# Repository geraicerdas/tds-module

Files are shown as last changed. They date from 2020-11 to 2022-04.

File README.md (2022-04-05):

### Repository Content
* **/firmware** : Arduino example codes (.ino)
* **/hardware** : Schematic files (.pdf) some of older version included Eagle design files (.sch and .brd)
* **/production** : gerber file for pcb manufacturing

You can purchase this product from  


# TDS Module

TDS (Total Dissolved Solids) indicates how many milligrams of soluble solids are dissolved in one liter of water. In general, the higher the TDS value, the more soluble solids are dissolved in water. This module can be used in DIY water quality application, such as domestic water analysis and hydroponics. The latest version already have temperature compensation for better accuracy.

<p float="left">
 

 
</p>

## How To Use
For the hardware you will need :
- Arduino or other compatible microcontroller
- TDS module with TDS probe and waterproof DS18B20
- Jumper wires

(optional : if you want to use Arduino Library) In the Arduino IDE, make sure :
- you have installed Library : [GravityTDS](https://github.com/DFRobot/GravityTDS) by DFRobot (This library tested on Arduino UNO, and will not work with Arduino Leonardo, ESP32)

Connect the TDS module to the MCU
| Arduino / Other MCU | TDS Module |
| --- |:---|
| 5V / 3.3V | VCC |
| Analog Input Pin | TDS |
| Digital Input Pin | TEM |
| GND | GND |

Upload the code in the firmware folder, and you will get the temperature and compensated TDS value of the water on the Serial Monitor

## Notice
- The probe can not to be used in water above 55 degrees centigrade.
- The probe can not be too close to the edge of the container, otherwise it will affect the reading

## Development logs
V3.0
- Add 3P PH2.0 connector for waterproof temperature sensor DS18B20
- Change 3P terminal to 4P terminal for additional temperature output pin

V2.1
- Rearrange component placement for better layout, fixing wrong decoupling capacitor position
- Change PCB color

V2.0
- Change PCB shape

V1.0
- Initial design

## PCB and Parts

If you want to make your self, just download the gerber file in production folder. Send it to your fav pcb manufacturer. And dont forget to get the Bill of materials :
|Qty | Part Name | Parts | MPN |
| --- |:---|:---| -----:|
|9|Capacitor 0603 100nF|C1, C2, C6, C7, C9, C11, C13, C16, C18|
|3|Capacitor 0603 10uF|C8, C10, C12|
|1|Capacitor 0603 1nF|C15|
|2|Capacitor 0603 1uF|C14, C17|
|2|Capacitor 0603 4.7uF|C4, C5|
|1|Capacitor 3216 100uF|C3|
|2|Resistor 0603 100K-1%|R4, R10|
|7|Resistor 0603 10K-1%|R5, R6, R7, R8, R9, R11, R12|
|1|Resistor 0603 1M-1%|R1|
|1|Resistor 0603 4K7-1%|R14|
|1|Resistor 0603 5.6K-1%|R2, R13|
|1|Resistor 0603 6.8K-1%|R3|
|5|Diode SOD-323 1N4148|D1, D2, D3, D4, D5|
|1|SMD LED 0805|L1|
|1|LMV324 SO-14|U1|
|1|TPS60400 SOT-23-5|U2|
|1|CD4060-BM SO-16|U3|
|1|XC6206P302MR SOT-23|U4|
|1|XH2.5 2P SMD connector|J3|
|1|PH2.0 3P SMD connector|J5|
|1|Teminal Connector 4P 5.08|J6|

Below is the previous version of our TDS Module. We keep this for your references.

### Version 2.1

<p float="left">
 

 
</p>

### Version 1.0

<p float="left">
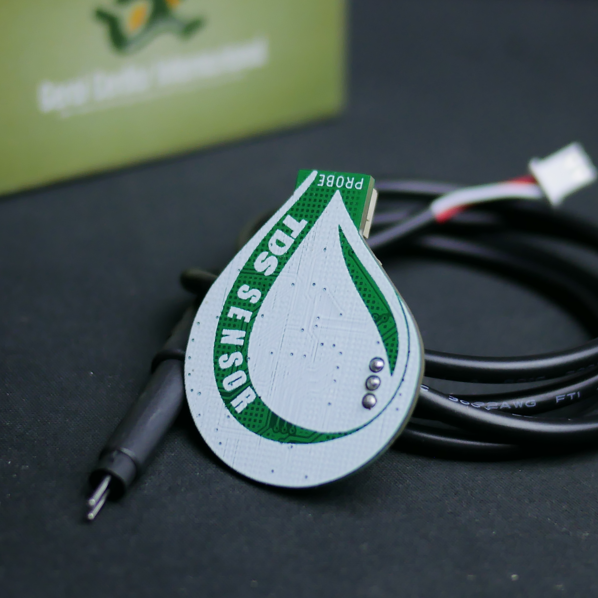
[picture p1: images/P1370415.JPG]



</p>

## License
*We invests time and resources providing this open-source hardware, please support us by purchasing our products.*

*Designed by **[Insan Sains](https://www.youtube.com/insansains)** for **[Gerai Cerdas](https://geraicerdas.com)**, with contributions from the open source community. Creative Commons Attribution/Share-Alike, all text above must be included in any redistribution. See license.txt for additional information.*

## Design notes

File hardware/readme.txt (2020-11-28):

For some reason the schematic with bottom silkscreen is larger than allowable github file size,
so the bottom silkscreen removed to reduce it size.

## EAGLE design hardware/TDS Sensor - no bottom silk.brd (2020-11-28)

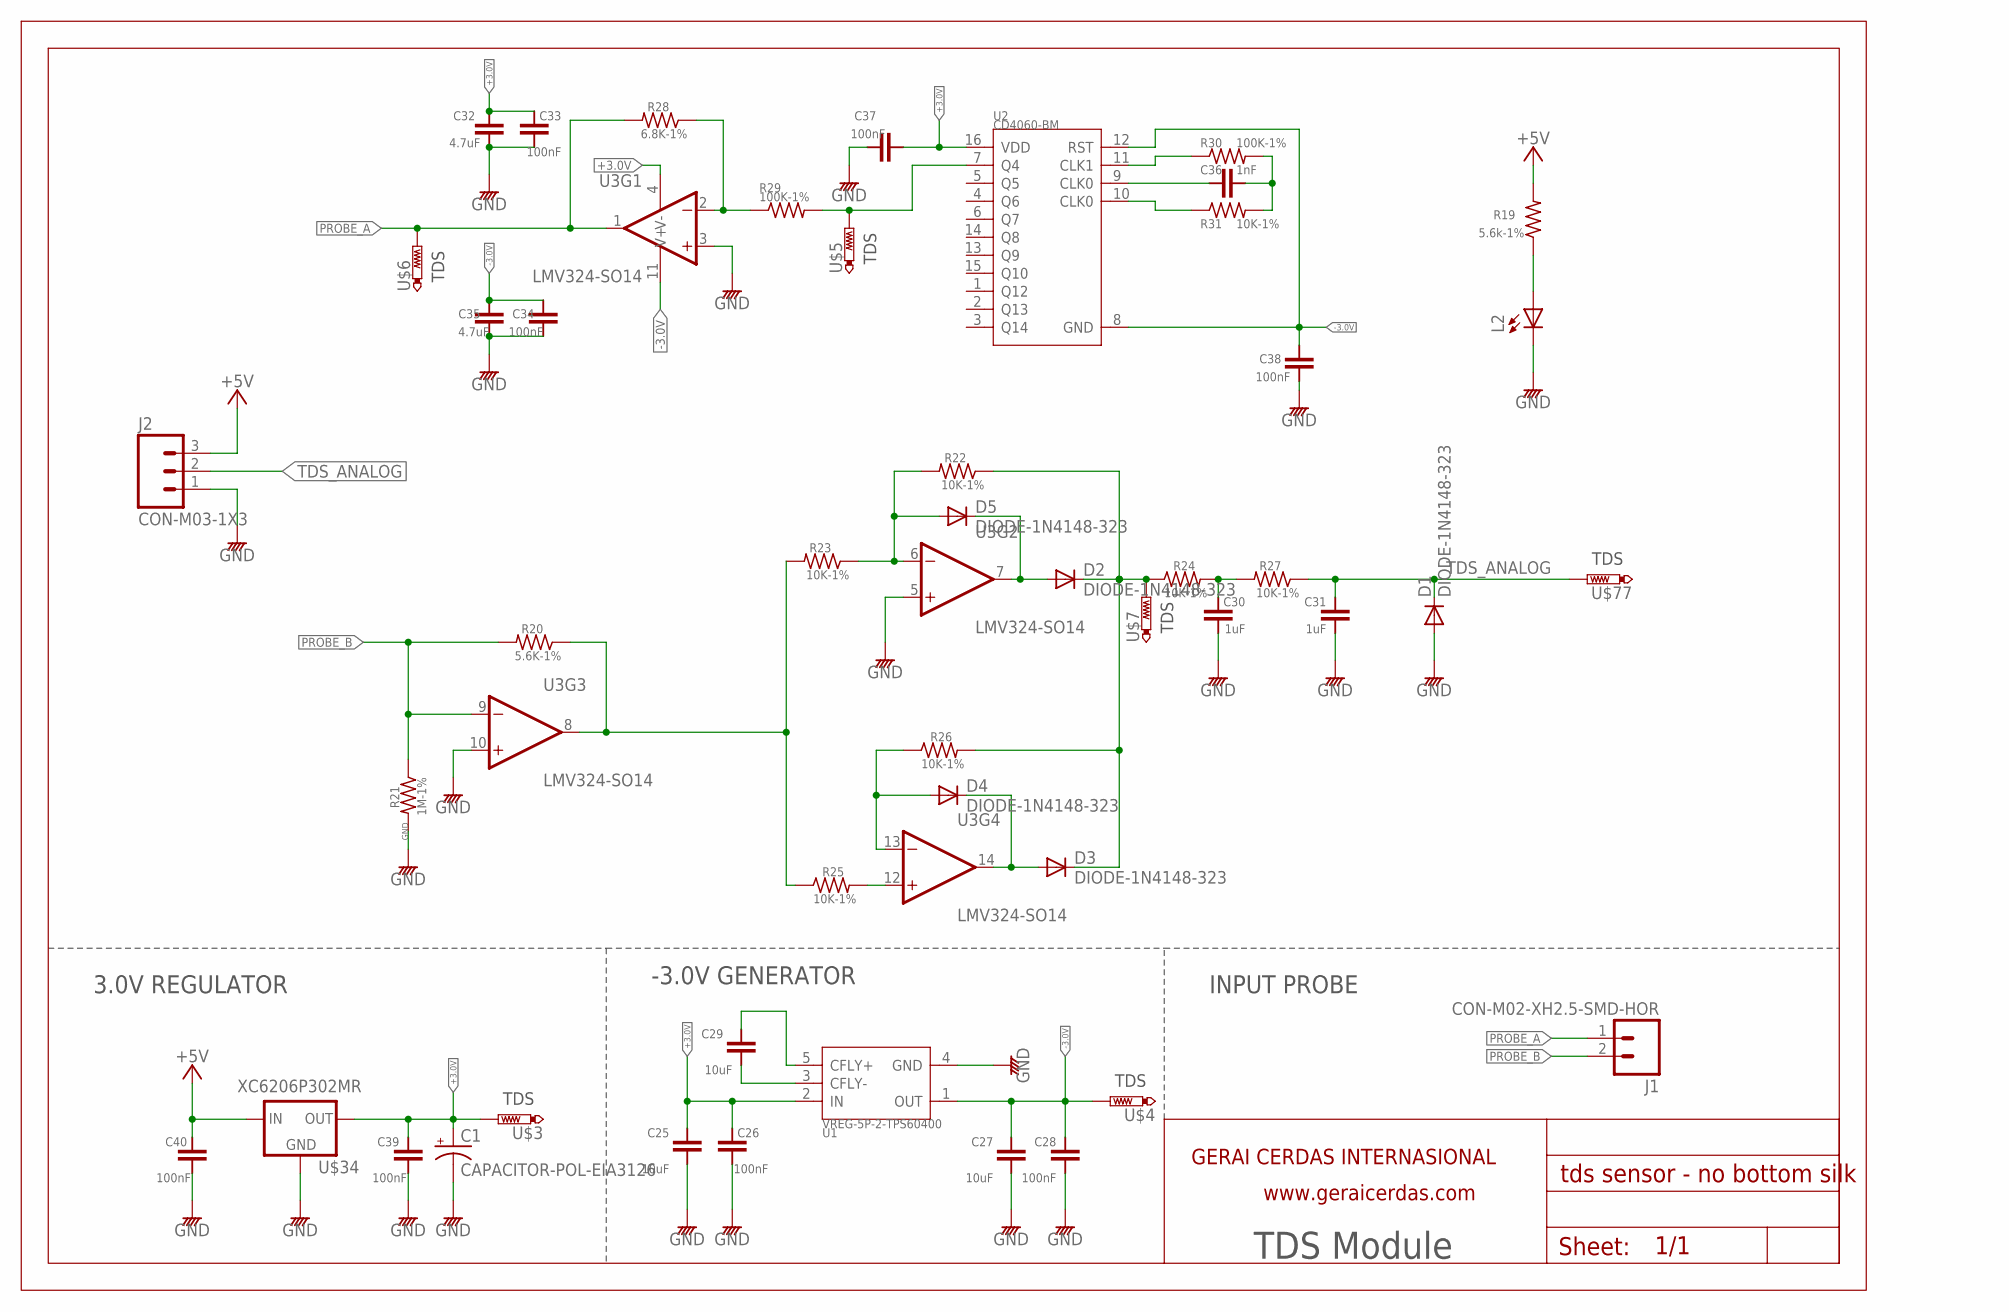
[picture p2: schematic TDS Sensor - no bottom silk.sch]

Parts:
C1: CAPACITOR-POL-EIA3126; EIA3126
C25, C27, C29: 10uF; C0603
C26, C28, C33, C34, C37, C38, C39, C40: 100nF; C0603
C30, C31: 1uF; C0603
C32, C35: 4.7uF; C0603
C36: 1nF; C0603
D1, D2, D3, D4, D5: DIODE-1N4148-323; SOD-323
J1: CON-M02-XH2.5-SMD-HOR; JST-XH2.5-2P-SMD-HORZ
J2: CON-M03-1X3; CON-M03X1
L2: LED-SMD0805; LED0805
R19: 5.6k-1%; R0603
R20: 5.6K-1%; R0603
R21: 1M-1%; R0603
R22, R23, R24, R25, R26, R27, R31: 10K-1%; R0603
R28: 6.8K-1%; R0603
R29, R30: 100K-1%; R0603
U1: VREG-5P-2-TPS60400; SOT-23-5
U2: CD4060-BM; SO-16
U3: LMV324-SO14; SO-14
U$3, U$4, U$5, U$6, U$7, U$77: TDS; TESTPAD_2.54
U$28: FRAME; A4-HOR
U$34: XC6206P302MR; SOT-23

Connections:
+3.0V: C1.A (+), C25.2, C26.2, C32.2, C33.2, C37.1, C39.2, U1.2 (IN), U2.16 (VDD), U3.4 (V+), U$3.TP, U$34.2 (OUT)
+5V: C40.2, J2.3, R19.2, U$34.3 (IN)
-3.0V: C27.2, C28.2, C34.2, C35.2, C38.2, U1.1 (OUT), U2.8 (GND), U2.12 (RST), U3.11 (V-), U$4.TP
GND: C1.C (-), C25.1, C26.1, C27.1, C28.1, C30.1, C31.1, C32.1, C33.1, C34.1, C35.1, C37.2, C38.1, C39.1, C40.1, D1.A, J2.1, L2.C, R21.2, U1.4 (GND), U3.3 (+IN), U3.5 (+IN), U3.10 (+IN), U$34.1 (ADJ)
unnamed: R25.2, U3.12 (+IN)
unnamed: L2.A, R19.1
unnamed: D5.A, R22.2, R23.1, U3.6 (-IN)
unnamed: D2.A, D5.C, U3.7 (OUT)
unnamed: D2.C, D3.C, R22.1, R24.1, R26.2, U$7.TP
unnamed: D4.A, R26.1, U3.13 (-IN)
unnamed: D3.A, D4.C, U3.14 (OUT)
unnamed: R20.1, R23.2, R25.1, U3.8 (OUT)
unnamed: C30.2, R24.2, R27.2
unnamed: R28.1, R29.1, U3.2 (-IN)
unnamed: C29.2, U1.5 (CFLY+)
unnamed: R30.1, U2.11 (CLK1)
unnamed: C36.1, U2.9 (CLK0)
unnamed: R31.1, U2.10 (CLK0)
unnamed: C36.2, R30.2, R31.2
unnamed: R29.2, U2.7 (Q4), U$5.TP
unnamed: C29.1, U1.3 (CFLY-)
PROBE_A: J1.1, R28.2, U3.1 (OUT), U$6.TP
PROBE_B: J1.2, R20.2, R21.1, U3.9 (-IN)
TDS_ANALOG: C31.2, D1.C, J2.2, R27.1, U$77.TP

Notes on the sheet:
TDS Module
INPUT PROBE
3.0V REGULATOR
-3.0V GENERATOR

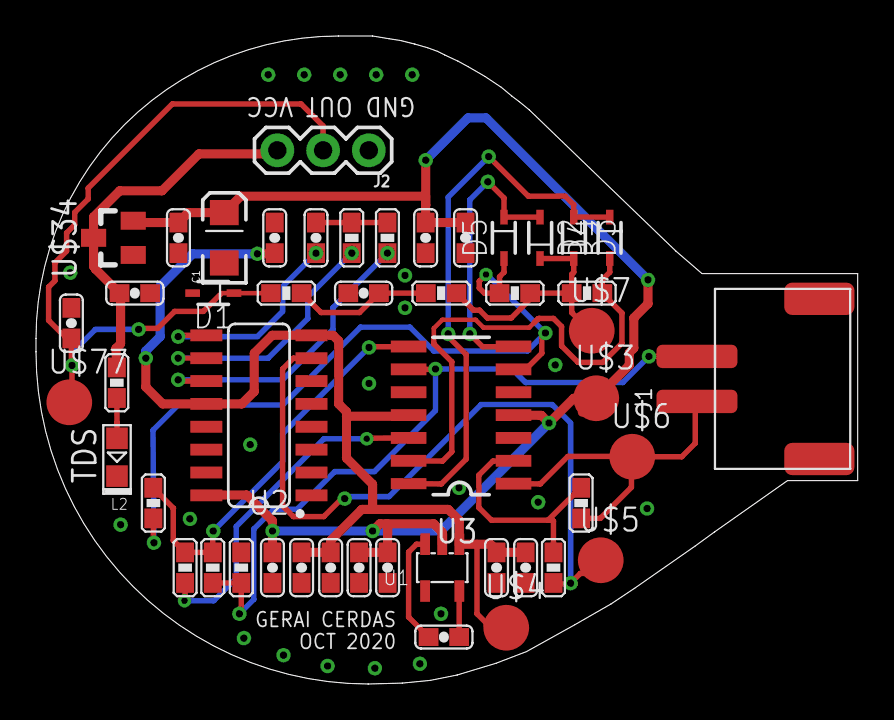
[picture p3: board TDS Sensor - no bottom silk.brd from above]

Board: 2 copper layers, 45.6 x 36.0 mm, 49 parts (0 on the bottom side), 24 nets.

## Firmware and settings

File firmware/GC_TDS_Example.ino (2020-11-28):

/***************************************************
 DFRobot Gravity: Analog TDS Sensor / Meter For Arduino
 <https://www.dfrobot.com/wiki/index.php/Gravity:_Analog_TDS_Sensor_/_Meter_For_Arduino_SKU:_SEN0244>

 Created 2017-8-22
 By Jason <jason.ling@dfrobot.com@dfrobot.com>

 GNU Lesser General Public License.
 See <http://www.gnu.org/licenses/> for details.
 All above must be included in any redistribution

 /***********Notice and Trouble shooting***************
 1. This code is tested on Arduino Uno and Leonardo with Arduino IDE 1.0.5 r2 and 1.8.2.
 2. More details, please click this link: <https://www.dfrobot.com/wiki/index.php/Gravity:_Analog_TDS_Sensor_/_Meter_For_Arduino_SKU:_SEN0244>
 ****************************************************/

#define TdsSensorPin A2
#define VREF 5.0      // analog reference voltage(Volt) of the ADC
#define SCOUNT  30           // sum of sample point
int analogBuffer[SCOUNT];    // store the analog value in the array, read from ADC
int analogBufferTemp[SCOUNT];
int analogBufferIndex = 0,copyIndex = 0;
float averageVoltage = 0,tdsValue = 0,temperature = 25;

void setup()
{
    Serial.begin(115200);
    pinMode(TdsSensorPin,INPUT);
}

void loop()
{
   static unsigned long analogSampleTimepoint = millis();
   if(millis()-analogSampleTimepoint > 40U)     //every 40 milliseconds,read the analog value from the ADC
   {
     analogSampleTimepoint = millis();
     analogBuffer[analogBufferIndex] = analogRead(TdsSensorPin);    //read the analog value and store into the buffer
     analogBufferIndex++;
     if(analogBufferIndex == SCOUNT) 
         analogBufferIndex = 0;
   }   
   static unsigned long printTimepoint = millis();
   if(millis()-printTimepoint > 800U)
   {
      printTimepoint = millis();
      for(copyIndex=0;copyIndex<SCOUNT;copyIndex++)
        analogBufferTemp[copyIndex]= analogBuffer[copyIndex];
      averageVoltage = getMedianNum(analogBufferTemp,SCOUNT) * (float)VREF / 1024.0; // read the analog value more stable by the median filtering algorithm, and convert to voltage value
      float compensationCoefficient=1.0+0.02*(temperature-25.0);    //temperature compensation formula: fFinalResult(25^C) = fFinalResult(current)/(1.0+0.02*(fTP-25.0));
      float compensationVolatge=averageVoltage/compensationCoefficient;  //temperature compensation
      tdsValue=(133.42*compensationVolatge*compensationVolatge*compensationVolatge - 255.86*compensationVolatge*compensationVolatge + 857.39*compensationVolatge)*0.5; //convert voltage value to tds value
      //Serial.print("voltage:");
      //Serial.print(averageVoltage,2);
      //Serial.print("V   ");
      Serial.print("TDS Value:");
      Serial.print(tdsValue,0);
      Serial.println("ppm");
   }
}
int getMedianNum(int bArray[], int iFilterLen) 
{
      int bTab[iFilterLen];
      for (byte i = 0; i<iFilterLen; i++)
      bTab[i] = bArray[i];
      int i, j, bTemp;
      for (j = 0; j < iFilterLen - 1; j++) 
      {
      for (i = 0; i < iFilterLen - j - 1; i++) 
          {
        if (bTab[i] > bTab[i + 1]) 
            {
        bTemp = bTab[i];
            bTab[i] = bTab[i + 1];
        bTab[i + 1] = bTemp;
         }
      }
      }
      if ((iFilterLen & 1) > 0)
    bTemp = bTab[(iFilterLen - 1) / 2];
      else
    bTemp = (bTab[iFilterLen / 2] + bTab[iFilterLen / 2 - 1]) / 2;
      return bTemp;
}

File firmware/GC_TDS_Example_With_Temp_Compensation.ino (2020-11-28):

/***************************************************
 DFRobot Gravity: Analog TDS Sensor/Meter
 <https://www.dfrobot.com/wiki/index.php/Gravity:_Analog_TDS_Sensor_/_Meter_For_Arduino_SKU:_SEN0244>
 
 ***************************************************
 This sample code shows how to read the tds value and calibrate it with the standard buffer solution.
 707ppm(1413us/cm)@25^c standard buffer solution is recommended.
 
 Created 2018-1-3
 By Jason <jason.ling@dfrobot.com@dfrobot.com>
 
 GNU Lesser General Public License.
 See <http://www.gnu.org/licenses/> for details.
 All above must be included in any redistribution.
 ****************************************************/
 
 /***********Notice and Trouble shooting***************
 1. This code is tested on Arduino Uno with Arduino IDE 1.0.5 r2 and 1.8.2.
 2. Calibration CMD:
     enter -> enter the calibration mode
     cal:tds value -> calibrate with the known tds value(25^c). e.g.cal:707
     exit -> save the parameters and exit the calibration mode
 ****************************************************/

#include <DS18B20.h>
DS18B20 ds(2);

#include <EEPROM.h>
#include "GravityTDS.h"

#define TdsSensorPin A2
GravityTDS gravityTds;

float temperature = 25,tdsValue = 0;

void setup()
{
    Serial.begin(9600);
    gravityTds.setPin(TdsSensorPin);
    gravityTds.setAref(5.0);  //reference voltage on ADC, default 5.0V on Arduino UNO
    gravityTds.setAdcRange(1024);  //1024 for 10bit ADC;4096 for 12bit ADC
    gravityTds.begin();  //initialization
}

void loop()
{
    temperature = ds.getTempC();    
    gravityTds.setTemperature(temperature);  // set the temperature and execute temperature compensation
    gravityTds.update();  //sample and calculate 
    tdsValue = gravityTds.getTdsValue();  // then get the value
    Serial.print(tdsValue,0);
    Serial.println("ppm");
    Serial.println(temperature);
    delay(1000);
}
